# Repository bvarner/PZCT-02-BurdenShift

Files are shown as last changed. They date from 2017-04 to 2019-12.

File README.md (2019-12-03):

# PZCT-02-BurdenShift
Resistive burden &amp; level shift to convert PZCT-02 Split-core Current Transformer output to ADC input voltages.

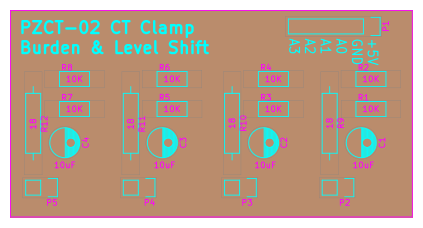
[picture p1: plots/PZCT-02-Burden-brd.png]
Component Side
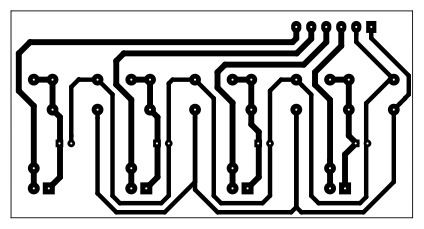
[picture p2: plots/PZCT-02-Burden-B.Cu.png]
Copper Side
 

In searching for split-core current transformers, I ran across the PZCT-02. A rather inexpensive split-core 100 Amp transformer.
[Amazon](https://www.amazon.com/s?k=PZCT-02+current+transformer)
[AliExpress](https://www.aliexpress.com/wholesale?SearchText=PZCT-02)

This circuit provides burden resistance, voltage division & test point shifting to feed measurements into an Analog to Digital Converter (ADC).

I've used this with the 10bit analog input pins on Arduino's, as well as an ADS1115 16-bit ADC hooked to a raspberry pi I2C bus.

Both approaches work well. But I prefer the 16bit resolution on the I2C bus of the Pi, which can be polled rediculously fast using Collectd and the 'sensors' plugin.

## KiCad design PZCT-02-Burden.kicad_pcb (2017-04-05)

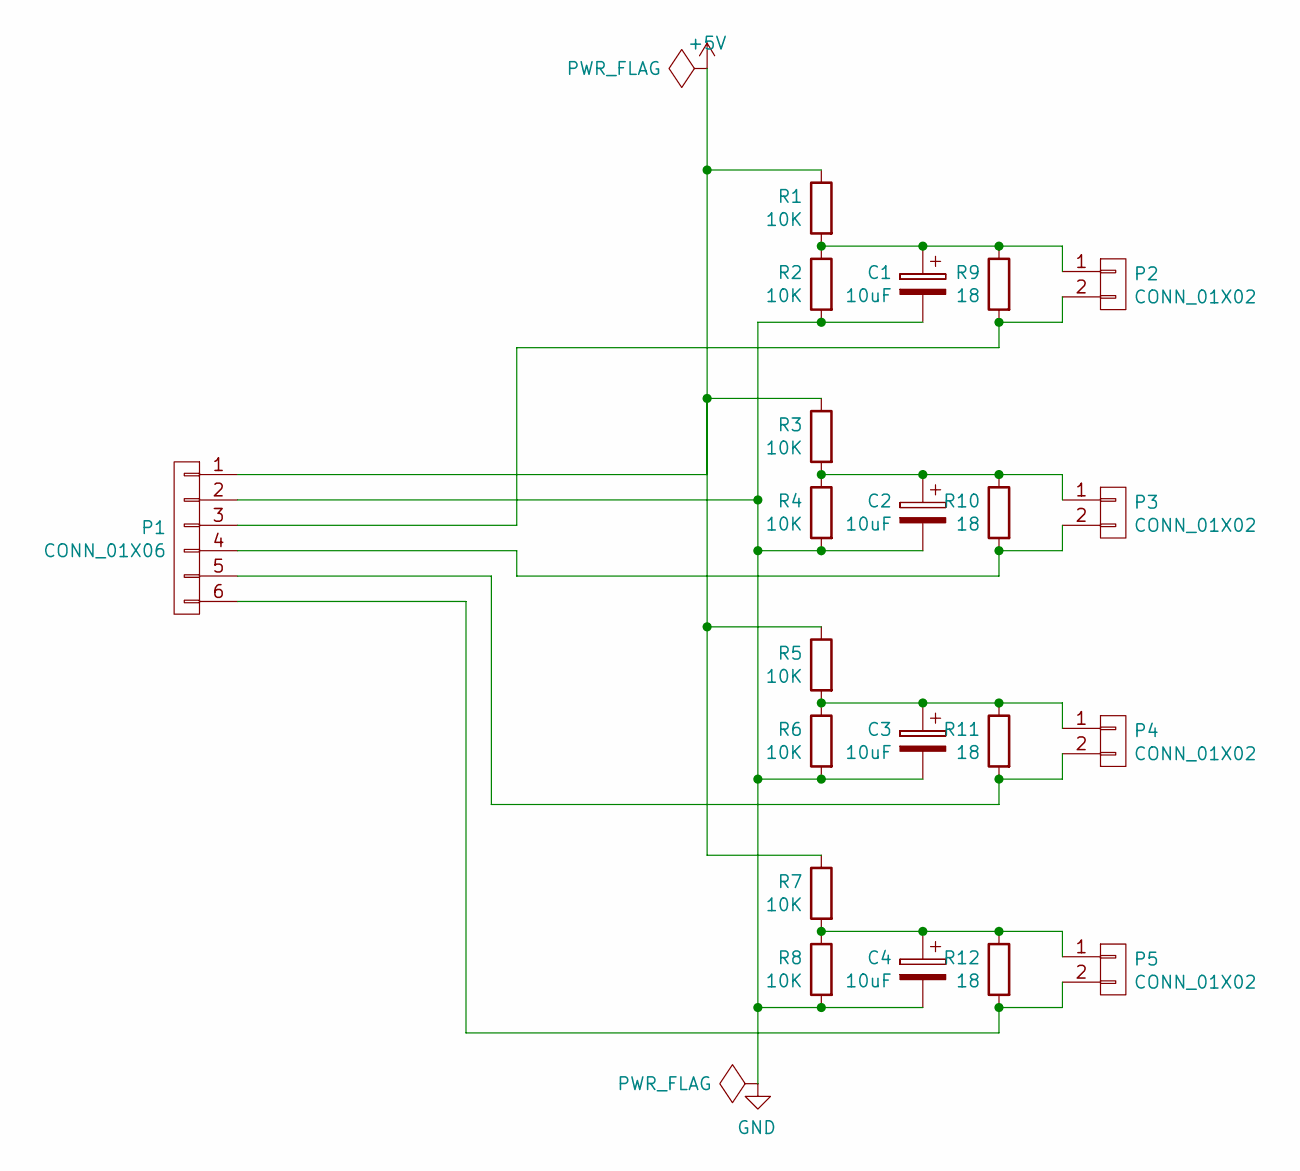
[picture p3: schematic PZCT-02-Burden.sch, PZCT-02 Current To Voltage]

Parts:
C1, C2, C3, C4: 10uF; C_Radial_D5_L11_P2
P1: CONN_01X06; Pin_Header_Straight_1x06
P2, P3, P4, P5: CONN_01X02; Pin_Header_Straight_1x02
R1, R2, R3, R4, R5, R6, R7, R8: 10K; Resistor_Horizontal_RM7mm
R9, R10, R11, R12: 18; Resistor_Horizontal_RM15mm

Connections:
+5V: P1.1, R1.1, R3.1, R5.1, R7.1
GND: C1.2, C2.2, C3.2, C4.2, P1.2, R2.2, R4.2, R6.2, R8.2
unnamed: C1.1, P2.1, R1.2, R2.1, R9.1
unnamed: C2.1, P3.1, R3.2, R4.1, R10.1
unnamed: C3.1, P4.1, R5.2, R6.1, R11.1
unnamed: C4.1, P5.1, R7.2, R8.1, R12.1
unnamed: P1.3, P2.2, R9.2
unnamed: P1.4, P3.2, R10.2
unnamed: P1.5, P4.2, R11.2
unnamed: P1.6, P5.2, R12.2

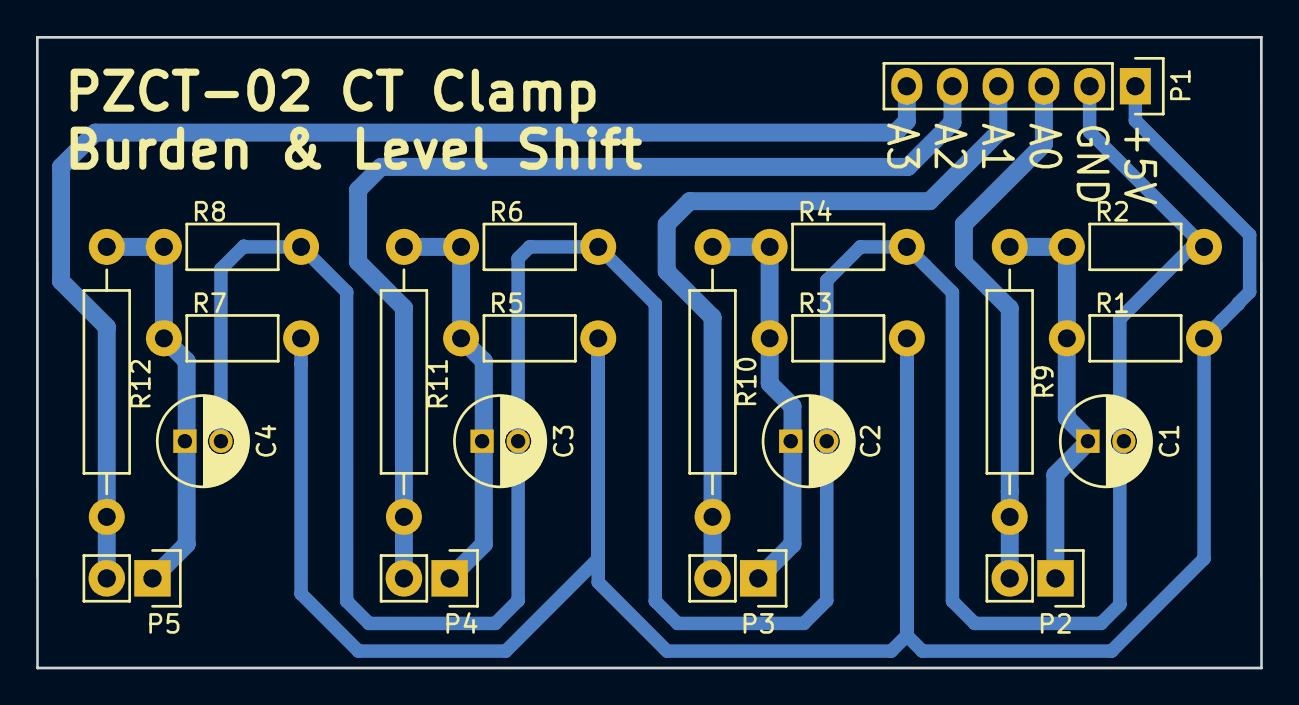
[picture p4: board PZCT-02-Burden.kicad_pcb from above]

Board: 2 copper layers, 68.0 x 35.0 mm, 21 parts (0 on the bottom side), 10 nets.

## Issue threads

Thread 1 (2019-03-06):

Calculation of current through pzct-02

mightyDipak, 2019-03-06:
Can you please explain how o measure current accurately. I got non linear results through it. using openenergymonitor :
https://github.com/openenergymonitor/EmonLib

What is turn ration inside it?
How you calculate 18ohm burden resistance.

bvarner, 2019-03-08:
Hi! It’s been a few years since I went through all this, and my math may be a bit off or my memory very fuzzy.

I found this link this evening
https://upcommons.upc.edu/bitstream/handle/2117/26509/IMS-SN2-1.pdf;jsessionid=EF765717C188F3E699561AE7B48E37ED?sequence=1

There’s other stuff out there on how to calculate or size these. Search around.

With the selections I made, my notes say this CT is a 1000:1, and after the resistor, 1mv represents 1ma through the measured line.

I use an ADS1115 for an ADC.

Interestingly enough, I just got some supplies to update this project and clean it up a bit. I planned on starting that in the coming weeks.

Best of luck to you!

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

mightyDipak, 2019-03-08:
Thanks for you reply.
CT ratio 1000:1, may help me lot.
If you datasheet of PZCT-02, then please share it.

bvarner, 2019-12-21:
I do not have a datasheet on the transformer. The markings on the side were what I went by.

Closed 2019-12-21.

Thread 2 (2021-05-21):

Exploring alternatives to PZCT-02

jalakamkiranadspl, 2021-05-21:
Hey @bvarner, Thanks for the design. It shares good knowledge. I am trying to find an alternative current transformer for the PZCT-02 which is rather very expensive. Initially I found the turns ratio to be 1000:1 with capability of measuring 100A. Did you come across any of them? I know this is completely unrelated to your repository but I thought you might shed some light on this since I am trying make the circuit out of it.

bvarner, 2021-05-21:
Yes, at $7 / per unit the PZCT-02 is a bit of a high price point compared to smaller diameter transformers.

Searching aliexpress for 1000:1 current transformers I found quite a few there.  IIRC you also need to account for the impedance of the transformer when sizing burden resistors. Good luck!

I chose the PZCT-02 as it was the cheapest thing I could find that would handle 200A.

norah555, 2025-07-10:
salut j'ai un capteur PZCT-02 mais je n'arrive pas à le relier à la carte ads puis au rasberry. Il ne faut pas rajouter de résistance entre le capteur et la carte ADS ?
